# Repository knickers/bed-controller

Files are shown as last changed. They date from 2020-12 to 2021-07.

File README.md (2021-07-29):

# Voice controlled hospital bed inclination

This is a more advanced control program for the Particle Argon WIFI microcontroller used in
[this Instructables hospital bed controller](https://www.instructables.com/Voice-Controlled-Hospital-Bed-by-Wifi/).
Instead of using multiple IFTTT recipes (one for up and one for down, for each joint,) this uses a single recipe, passing an entire command string to the Particle microcontroller. Then a state machine parses the sudo-natural language commands.

*Digital assistant trigger* **move the bed** *command string*

*Hey Google, move the bed up 20 degrees.*

*Hey Google, move the bed legs up 10 degrees.*

*Hey Google, move the bed down.*

*Hey Google, move the bed up halfway.*

*Hey Google, stop the bed now.*

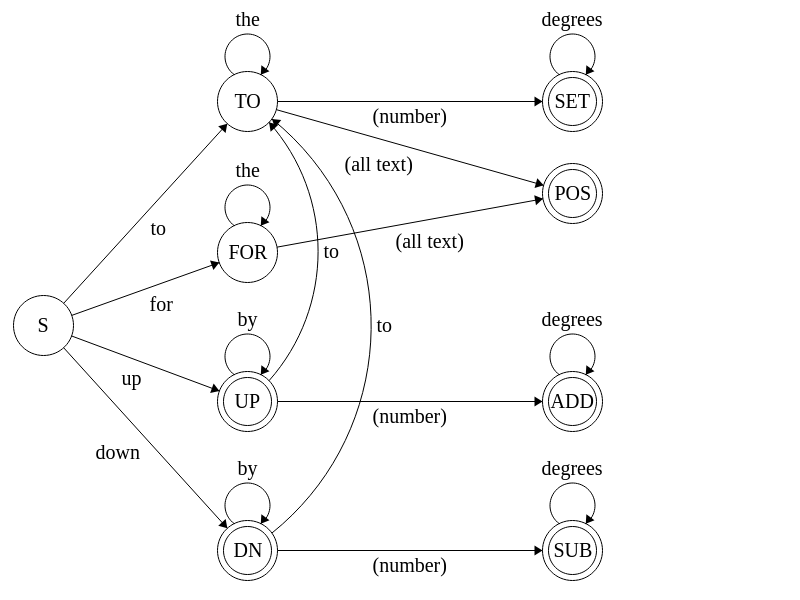
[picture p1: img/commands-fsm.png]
Command Finite State Machine


## Named positions

- halfway
	- Move head by 35 degrees
	- Move feet by 17 degrees
- all the way
	- Move head by 50 degrees
	- Move feet by 25 degrees

## Tasks

- [x] Parse commands
	- [x] Use a single IFTTT recipe
	- [x] String tokenizer
	- [x] State machine command parser
- [ ] Time-based angle estimation
	- [x] Calculate duration from estimated actuator speed
	- [ ] Account for actuator acceleration and deceleration time
- [ ] Measure DC current through pendant switches
	- [ ] Watch DC current to track actuator load and end-stops
	- [ ] Preload joint slop after detecting actuator end-stop
- [ ] Measure angle directly at bed joint
	- [x] Hall effect angle sensor
	- [ ] Calibrate sensor reading map to real angle

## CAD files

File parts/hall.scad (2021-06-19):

// Space between moving parts
tolerance = 0.2; // [0.05:0.05:0.5]

// Wall Thickness
wall = 2; // [1:0.5:5]

// Steel Thickness
steel = 5; // [2:0.5:10]

// Rivet Diameter
rivet = 19.5; // [15:0.5:25]

// Radius to Support Block
radius = 20; // [10:1:30]

// Magnet Diameter
magnet_d = 8; // [1:1:20]

// Magnet Height
magnet_h = 3; // [1:0.5:5]

// Angle Between Magnets
magnet_a = 65; // [20:1:90]

// Distance Between Magnets
distance = 15; // [10:1:20]

// Radius to center of magnet arc
magnet_r = distance/2 / sin(magnet_a/2);

// Resolution
$fs = 2; // [1:High, 2:Medium, 4:Low]
$fa = 0.01 + 0;

part = "Combined"; // [Combined, Separated, Rotor, Stator Front, Stator Back]

if (part == "Combined") {
	difference() {
		union() {
			translate([0, 0, magnet_h+wall*2+tolerance])
				rotate(180, [1,0,0])
					color("red") stator_back();

			rotate(magnet_a/2, [0,0,1])
				translate([0, 0, -wall*2-tolerance])
					color("blue") stator_front();

			translate([0, 0, 0])
				rotor();
		}
		translate([0, 0, -rivet/2])
			cube(rivet);
	}
}
else if (part == "Separated") {
	translate([-rivet, 0, 0])
		rotor();
	translate([rivet, 0, 0])
		stator_front();
	translate([0, rivet, 0])
		stator_back();
}
else if (part == "Rotor") {
	rotor();
}
else if (part == "Stator Front") {
	stator_front();
}
else if (part == "Stator Back") {
	stator_back();
}

module stator_front() {
	flange = rivet+wall*0+tolerance*2;
	difference() {
		union() {
			cylinder(d=rivet-wall*4, h=wall*3); // Insert
			cylinder(d=flange, h=wall*2);       // Flange
			linear_extrude(wall)
				polygon([                       // Sensor tab
					[-magnet_r-2, 2],    // Q2
					[-magnet_r-2, -2],   // Q3
					[-rivet/2+wall, -wall*3], // Q4
					[-rivet/2+wall, wall*3]   // Q1
				]);
		}
		translate([0, 0, -1])
			cylinder(d=rivet-wall*6, h=wall*3+2, $fn=7);// Center Hole
		translate([-flange/2.025-1, -1.5, -1])
			cube([1, 3, wall*2+2]);               // Vertical Wire Cutout
		translate([-rivet, -1.5, wall])
			cube([rivet, 3, 1]);               // Horizontal Wire Cutout
	}
}

module stator_back() {
	h = magnet_h + wall*2 + tolerance*2;
	flange = rivet + wall*2 + tolerance*2;

	difference() {
		union() {
			cylinder(d=rivet-wall*2, h=h);                // OD
			cylinder(d=flange, h=wall*2);                 // Flange
		}

		translate([0, 0, wall*2])
			cylinder(d=rivet-wall*4, h=wall*2);           // ID

		translate([0, 0, -1])
			cylinder(d=rivet, h=wall+1);                  // Rivet cutout

		translate([-flange/2, rivet/2, 0])
			rotate(-45, [1,0,0])
				cube([flange, wall*2, h]);                // Steel corner cutout

		//translate([0, 0, -1]) cube(rivet);
	}
}

module rotor() {
	or = rivet/2 + tolerance; // Outside Radius
	mag = magnet_d / 2;

	difference() {
		union() {
			translate([-radius-mag-wall, 0, 0])
				cylinder(r=mag+wall, h=magnet_h+steel+wall*2+tolerance);
					// Support block

			linear_extrude(magnet_h)
				hull() {
					circle(or);

					rotate(-magnet_a/2, [0,0,1])
						translate([-magnet_r, 0, 0])
							circle(mag + wall);        // Upper magnet

					rotate(magnet_a/2, [0,0,1])
						translate([-magnet_r, 0, 0])
							circle(mag + wall);        // Lower magnet

					translate([-radius-mag-wall, 0, 0])
						circle(mag + wall);            // Support Block
				}
		}

		translate([0, 0, -1])
			cylinder(r=or-wall, h=magnet_h+2);         // ID

		rotate(-magnet_a/2, [0,0,1])
			translate([-magnet_r, 0, -1])
				cylinder(d=magnet_d+tolerance, h=magnet_h+tolerance+2); // Upper

		rotate(magnet_a/2, [0,0,1])
			translate([-magnet_r, 0, -1])
				cylinder(d=magnet_d+tolerance, h=magnet_h+tolerance+2); // Lower
	}
}

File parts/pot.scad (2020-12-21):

// Tolerance between moving parts
T  = 0.2;   // [0.1:0.05:0.5]
T2 = T / 2; // Half of the part tolerance

S  = 4;     // Steel thickness
P  = 2 + 0; // Perimeter wall thickness

$fn = 16;


/***************************************
 *  Layout all the parts for printing  *
 ***************************************
 */

/* * /
head_dynamic();
/* */

/* */
head_static();
/* */

/************************************
 *  Modules for building each part  *
 ************************************
 */

module head_dynamic() {
	x = 15;
	y = 15;
	d = 30;
	r = 3;

	// Clip
	difference() {
		cube([x, y, S+2*P]);
		translate([P, P, P])
			cube([x, y, S]);
	}

	// Pot shaft plate
	translate([0, P-d, -7]) {
		difference() {
			union() {
				translate([0, r-1, -r-P])
					cube([P, d+y-r-P+1, 12+P]); // Main plate
				rotate(90, [0,1,0])
					cylinder(r=r+P, h=P*2); // Flex clip
			}

			translate([-1, 0, 0])
				rotate(90, [0,1,0]) {
					cylinder(r=r, h=P*2+2); // Center hole

					translate([-12-1, r-1, 0])
						cube([12+1, 1, P*2+2]); // Flex cutout

					/*
					difference() { // Corner rounder
						translate([-10, -10, 0])
							cube([16, 10, P+2]);
						translate([0, 0, -2])
							cylinder(r=r+P, h=P+4);
					}

					translate([-r-r-P-P, -1, 0])
						cube([r+P, d-P+1, P+2]); // Flatten top
					*/
				}
		}
	}
}

module head_static() {
	x = 10;
	y = 20;
	d = 15;
	dowelLength = 16;

	// Clip
	difference() {
		translate([0, -P, -P])
			cube([x, y, S+2*P]);
		translate([-1, 0, 0])
			cube([x+2, y, S]);
	}

	// Extension arm
	translate([0, -d-12, S])
		cube([x, d+12, P]);

	// Pot mounting plate
	translate([x-P, -d, -8.5]) {
		difference() {
			translate([0 , -12, -10])
				cube([P, 25+P, 10+12.5+P]); // Main plate

			translate([-1, 0, 0])
				rotate(90, [0,1,0])
					cylinder(d=7.5, h=P+2); // Center hole

			translate([-1 , -1-12, -1.5])
				cube([P+2, 2+1, 3]); // Key notch
		}
	}
}

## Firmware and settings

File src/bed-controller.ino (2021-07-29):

#include "Particle.h"
#include <BedJoint.h>
#include <StateMachine.h>
#include <Tokenizer.h>

#define PIN_HEAD_UP 0
#define PIN_HEAD_DN 1
#define PIN_FEET_UP 2
#define PIN_FEET_DN 3

#define ANGLE_UP   20
#define ANGLE_HALF 35
#define ANGLE_FULL 50
#define ANGLE_MAX  60

// Head bottom slop ~~ 2 sec ~~ 8 degrees

BedJoint  head(PIN_HEAD_UP, PIN_HEAD_DN);
BedJoint  feet(PIN_FEET_UP, PIN_FEET_DN);
BedJoint* joint;
int8_t dir;

StateMachine parser = StateMachine();

Tokenizer token = Tokenizer();
void nextToken() { token.next(); }

/*******************************************************************/
/**************************** States *******************************/
/*******************************************************************/

State* s_start = parser.addState(&nextToken);
State* s_for   = parser.addState(&nextToken);
State* s_to    = parser.addState([]() {
	token.next();

	if (token.eq("") || token.eq("degrees")) {
		joint->addAngle(2);
	}
});
State* s_up    = parser.addState([]() {
	token.next();

	if (token.eq("")) {
		joint->addAngle(ANGLE_UP);
	}
});
State* s_down = parser.addState([]() {
	token.next();

	dir = -1;

	if (token.eq("")) {
		joint->addAngle(-ANGLE_UP);
	}
});
State* s_add = parser.addState([]() {
	if (parser.executeOnce) {
		joint->addAngle(dir * round(token.toFloat()));
	}

	token.next();
});
State* s_pos = parser.addState([]() {
	if (parser.executeOnce) {
		token.remaining();
		token.trimEnd("position");
		token.trimEnd("up");
		if (token.trimEnd("down")) {
			dir = -1;
		}
	}
});
State* s_err = parser.addState([]() {
	head.turnOff();
	feet.turnOff();
	publish("bed/error", "Invalid named position: '" + token.val() + "'");
});


/********************************************************************/
/**************************** Positions *****************************/
/********************************************************************/

State* p_up   = parser.addState([]() { joint->addAngle(ANGLE_UP); });
State* p_down = parser.addState([]() { joint->addAngle(-ANGLE_FULL); });
State* p_half = parser.addState([]() { joint->addAngle(ANGLE_HALF); });
State* p_full = parser.addState([]() { joint->addAngle(ANGLE_FULL); });
State* p_off  = parser.addState([]() { head.turnOff(); feet.turnOff(); });
State* p_alltheway = parser.addState([]() {
	head.addAngle(dir * ANGLE_FULL);
	feet.addDelay(dir * ANGLE_FULL/2, 500);
});
State* p_halfway = parser.addState([]() {
	head.addAngle(dir * ANGLE_HALF);
	feet.addDelay(dir * ANGLE_HALF/2, 500);
});


/********************************************************************/
/************************** Transitions *****************************/
/********************************************************************/

bool t_feet() {
	if (token.eq("feet") ||
		token.eq("legs") ||
		token.eq("knees")
	) {
		joint = &feet;
		return true;
	}
	return false;
}
bool t_head() {
	bool ok = token.eq("head");
	if (ok || joint == NULL) {
		joint = &head;
	}
	return ok;
}
bool t_to()   { return token.eq("to") || token.eq("too"); }
bool t_for()  { return token.eq("for"); }
bool t_up()   { return token.eq("up") || token.eq("of"); }
bool t_down() { return token.eq("down"); }
bool t_by()   { return token.eq("by"); }
bool t_the()  { return token.eq("the"); }
bool t_num()  { return token.isNumeric(); }
bool t_all()  { return !token.eq(""); }
bool t_deg()  {
	return token.eq("degrees") || token.eq("degree") || token.eq("°"); // \u00B0
}


void setup() {
	Particle.function("command", executeCommand);
	Particle.function("headAngle", setHeadAngle);
	Particle.function("feetAngle", setFeetAngle);

	pinMode(PIN_HEAD_UP, OUTPUT);
	pinMode(PIN_HEAD_DN, OUTPUT);
	pinMode(PIN_FEET_UP, OUTPUT);
	pinMode(PIN_FEET_DN, OUTPUT);

	// StateMachine Transitions
	s_start->addTransition(&t_feet, s_start);
	s_start->addTransition(&t_head, s_start);
	s_start->addTransition(&t_to,   s_to);
	s_start->addTransition(&t_for,  s_for);
	s_start->addTransition(&t_up,   s_up);
	s_start->addTransition(&t_down, s_down);
	s_start->addTransition(&t_all,  s_pos);
	s_start->addTransition([]() { return token.eq(""); }, p_off);

	s_to->addTransition(&t_the, s_to);
	s_to->addTransition(&t_num, s_add);
	s_to->addTransition(&t_all, s_pos);

	s_for->addTransition(&t_the, s_for);
	s_for->addTransition(&t_all, s_pos);

	s_up->addTransition(&t_to,  s_to);
	s_up->addTransition(&t_by,  s_up);
	s_up->addTransition(&t_for, s_for);
	s_up->addTransition(&t_num, s_add);
	s_up->addTransition(&t_all, s_pos);

	s_down->addTransition(&t_to,  s_to);
	s_down->addTransition(&t_by,  s_down);
	s_down->addTransition(&t_for, s_for);
	s_down->addTransition(&t_num, s_add);
	s_down->addTransition(&t_all, s_pos);

	s_add->addTransition(&t_deg, s_add);

	// Named Positions
	s_pos->addTransition(&t_up, p_up);
	s_pos->addTransition(&t_down, p_down);
	s_pos->addTransition([]() { return token.eq("bottom"); }, p_down);

	s_pos->addTransition([]() { return token.eq("halfway");     }, p_halfway);
	s_pos->addTransition([]() { return token.eq("half way");    }, p_halfway);
	s_pos->addTransition([]() { return token.eq("all the way"); }, p_alltheway);

	s_pos->addTransition([]() { return token.eq("");       }, p_off);
	s_pos->addTransition([]() { return token.eq("now");    }, p_off);
	s_pos->addTransition([]() { return token.eq("off");    }, p_off);
	s_pos->addTransition([]() { return token.eq("stop");   }, p_off);
	s_pos->addTransition([]() { return token.eq("cancel"); }, p_off);

	s_pos->addTransition(&t_all, s_err);

	//Serial.begin(115200);
}

void loop() {
	head.update();
	feet.update();
}

void publish(String event, String data) {
	if (Serial.isConnected()) {
		Serial.printlnf("%d %s: %s", (int)Time.now(), event.c_str(), data.c_str());
	}
	if (Particle.connected()) {
		Particle.publish(event, data, PRIVATE);
	}
}


/********************************************************************/
/************************ Particle Methods **************************/
/********************************************************************/

int executeCommand(String cmd) {
	cmd.trim();
	cmd.toLowerCase();

	publish("bed/command", cmd);

	joint = NULL;
	dir = 1;

	token.set(cmd);

	parser.exec();

	return 1;
}

int setHeadAngle(String angle) {
	if (Serial.isConnected()) {
		Serial.printlnf("%s Set head angle: %s",
			Time.format(TIME_FORMAT_ISO8601_FULL).c_str(),
			angle.c_str()
		);
	}
	head.addAngle(angle.toInt());
	return head.getState();
}

int setFeetAngle(String angle) {
	if (Serial.isConnected()) {
		Serial.printlnf("%s Set feet angle: %s",
			Time.format(TIME_FORMAT_ISO8601_FULL).c_str(),
			angle.c_str()
		);
	}
	feet.addAngle(angle.toInt());
	return feet.getState();
}

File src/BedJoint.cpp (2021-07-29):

#include "BedJoint.h"

BedJoint::BedJoint(int upPin, int downPin) {
	_state       = OFF;
	_pinUp       = upPin;
	_pinDown     = downPin;
	_target      = 0;                 // Milliseconds target to end movement
	_waitTill    = 0;
	_waitAngle   = 0;
	_rampUp      = 100;               // Milliseconds to ramp up to full speed
	_rampDown    = 500;               // Milliseconds to coast down to stop
	_millisAngle = 305;               // Milliseconds per angle in degrees
	_max         = _millisAngle * 60; // Maximum milliseconds to remain on
}

void BedJoint::turnOff() {
	_state = OFF;
	// Turn switches off
	digitalWrite(_pinUp, LOW);
	digitalWrite(_pinDown, LOW);
}

void BedJoint::update() {
	uint64_t now = System.millis();

	if (_waitTill && now >= _waitTill) {
		_waitTill = 0;
		addAngle(_waitAngle);
		_waitAngle = 0;
	}

	if (_state == OFF) {
		return;
	}

	// If the bed has been on long enough
	if (now >= _target || now >= _started+_max) {
		turnOff();
	}
}

void BedJoint::addAngle(int angle) {
	if (Serial.isConnected()) {
		Serial.printlnf("Adding angle: '%d'", angle);
	}

	turnOff();

	_started = System.millis();

	// TODO account for ramp up and down
	_target = abs(angle)*_millisAngle + _started;

	if (angle > 0) {
		_state = RAISING;
		// Turn on the up switch
		digitalWrite(_pinUp, HIGH);
	}
	else if (angle < 0) {
		_state = LOWERING;
		// Turn on the down switch
		digitalWrite(_pinDown, HIGH);
	}
}

void BedJoint::addDelay(int angle, uint32_t delay) {
	if (Serial.isConnected()) {
		Serial.printlnf("Delaying %d milliseconds before adding angle: '%d'",
			(int)delay,
			angle
		);
	}

	_waitTill = System.millis() + delay;
	_waitAngle = angle;
}

STATE BedJoint::getState() {
	return _state;
}

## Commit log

2020-12-18 Add source files
    [pot.scad]
2020-12-18 Ignore stl files
2020-12-18 Pot - Head dynamic arm on other plane
    [pot.scad]
2020-12-20 Pot head dynamic shaft holder
    [pot.scad]
2020-12-21 Make sure the bed is moving if in a moving state
2020-12-21 Pot head dynamic flex shaft holder
    [pot.scad]
2021-05-18 Untested bed class
2021-05-19 Max and min bed joint angle checks
2021-05-19 Fix some command parser errors.
    [bed-controller.ino]
2021-05-19 Move bed joint class into src directory
2021-05-22 Fix BedJoint class syntax errors
    [BedJoint.cpp, bed-controller.ino]
2021-05-24 Start bed endstop switch support
2021-05-31 Hall sensor 3d print parts
    [hall.scad]
2021-05-31 Add initial endstop button support
2021-06-08 Work on hall sensor positioner
    [hall.scad]
2021-06-08 Serial print the angle readings for the plotter
2021-06-08 Extend magnet holder down to print bed
    [hall.scad]
2021-06-08 Trapezoidal sensor tab holder
    [hall.scad]
2021-06-08 Begin the part chooser
    [hall.scad]
2021-06-08 Approximate min bed sensor reading
2021-06-08 Split stationary part for printing and assembly
    [hall.scad]
2021-06-08 Fix motor angle *grimace*
    [hall.scad]
2021-06-08 Redesign rotor
    [hall.scad]
2021-06-09 Separate hall magnets from support post
    [hall.scad]
2021-06-09 Separated parts spacing
    [hall.scad]
2021-06-09 Remove part height and use magnet height
    [hall.scad]
2021-06-11 Bigger hall sensor pad
    [hall.scad]
2021-06-11 Stator angle iron corner bend radius cutout
    [hall.scad]
2021-06-11 X-ray cutout for combined parts
    [hall.scad]
2021-06-19 Smaller hall hinge neck
    [hall.scad]
2021-06-22 Remove sensors from BedJoint
2021-06-23 Fix max on duration
    [BedJoint.cpp]
2021-06-24 Closer milliseconds per angle approximation
2021-07-05 Track command direction
